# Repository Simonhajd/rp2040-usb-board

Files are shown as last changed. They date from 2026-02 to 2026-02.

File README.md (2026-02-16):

# RP2040 USB Board (12×38mm)

A minimal RP2040 USB device board designed to fit within a 12mm × 38mm footprint, which is roughly the size of a small USB drive.

This project started from an RP2040 reference design and was stripped down to only the systems required for the USB device operation. I changed the flash and power components and entirely redesigned the layout to meet the width constraint, which matches the width of a standard USB port.




Screenshot 2026-02-16 at 4 23 13 PM

---

## What’s On It

* RP2040 (QFN)
* External QSPI flash
* 3.3V regulator
* Native USB interface
* Single status LED
* 2-layer PCB

There's no GPIO breakout since I intended to make a compact reliable RP2040 rather than a development board.

---

## Why

I wanted to see how small a functional RP2040 implementation could reasonably be made while still following the datasheet requirements.

The goal wasn’t to create a dev board, but a compact usb device.

---

## Status

Rev A boards are currently in fabrication and will be tested upon arrival.

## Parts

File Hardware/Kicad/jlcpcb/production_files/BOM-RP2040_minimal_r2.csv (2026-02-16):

Comment | Designator | Footprint | LCSC | Quantity
1u | C10 | C_0402_1005Metric |  | 1
27 | R4 | R_0402_1005Metric |  | 1
100n | C6 | C_0402_1005Metric |  | 1
100n | C12 | C_0402_1005Metric |  | 1
100n | C9 | C_0402_1005Metric |  | 1
27 | R3 | R_0402_1005Metric |  | 1
5.7K | R7 | R_0402_1005Metric |  | 1
AP2112K-3.3TRG1 | U4 | SOT95P285X140-5N |  | 1
4.7U | C1 | C_0402_1005Metric |  | 1
4.7U | C4 | C_0402_1005Metric |  | 1
1u | C8 | C_0402_1005Metric |  | 1
100n | C15 | C_0402_1005Metric |  | 1
5.7K | R6 | R_0402_1005Metric |  | 1
100n | C7 | C_0402_1005Metric |  | 1
ABM8-272-T3 | Y1 | Crystal_SMD_3225-4Pin_3.2x2.5mm |  | 1
100n | C5 | C_0402_1005Metric |  | 1
W25Q128JVS | U2 | Winbond_USON-8-1EP_3x2mm_P0.5mm_EP0.2x1.6mm |  | 1
RP2040 | U3 | RP2040-QFN-56 |  | 1
100n | C14 | C_0402_1005Metric |  | 1
100n | C11 | C_0402_1005Metric |  | 1
1k | R5 | R_0402_1005Metric |  | 1
DNF | R2 | R_0402_1005Metric |  | 1
15p | C3 | C_0402_1005Metric |  | 1
15p | C2 | C_0402_1005Metric |  | 1
100n | C13 | C_0402_1005Metric |  | 1
~ | 1 | USB-C-SMD_TYPE-C-31-G-09 |  | 1
470 | R8 | C_0402_1005Metric |  | 1
LED | D1 | LED_0603_1608Metric |  | 1

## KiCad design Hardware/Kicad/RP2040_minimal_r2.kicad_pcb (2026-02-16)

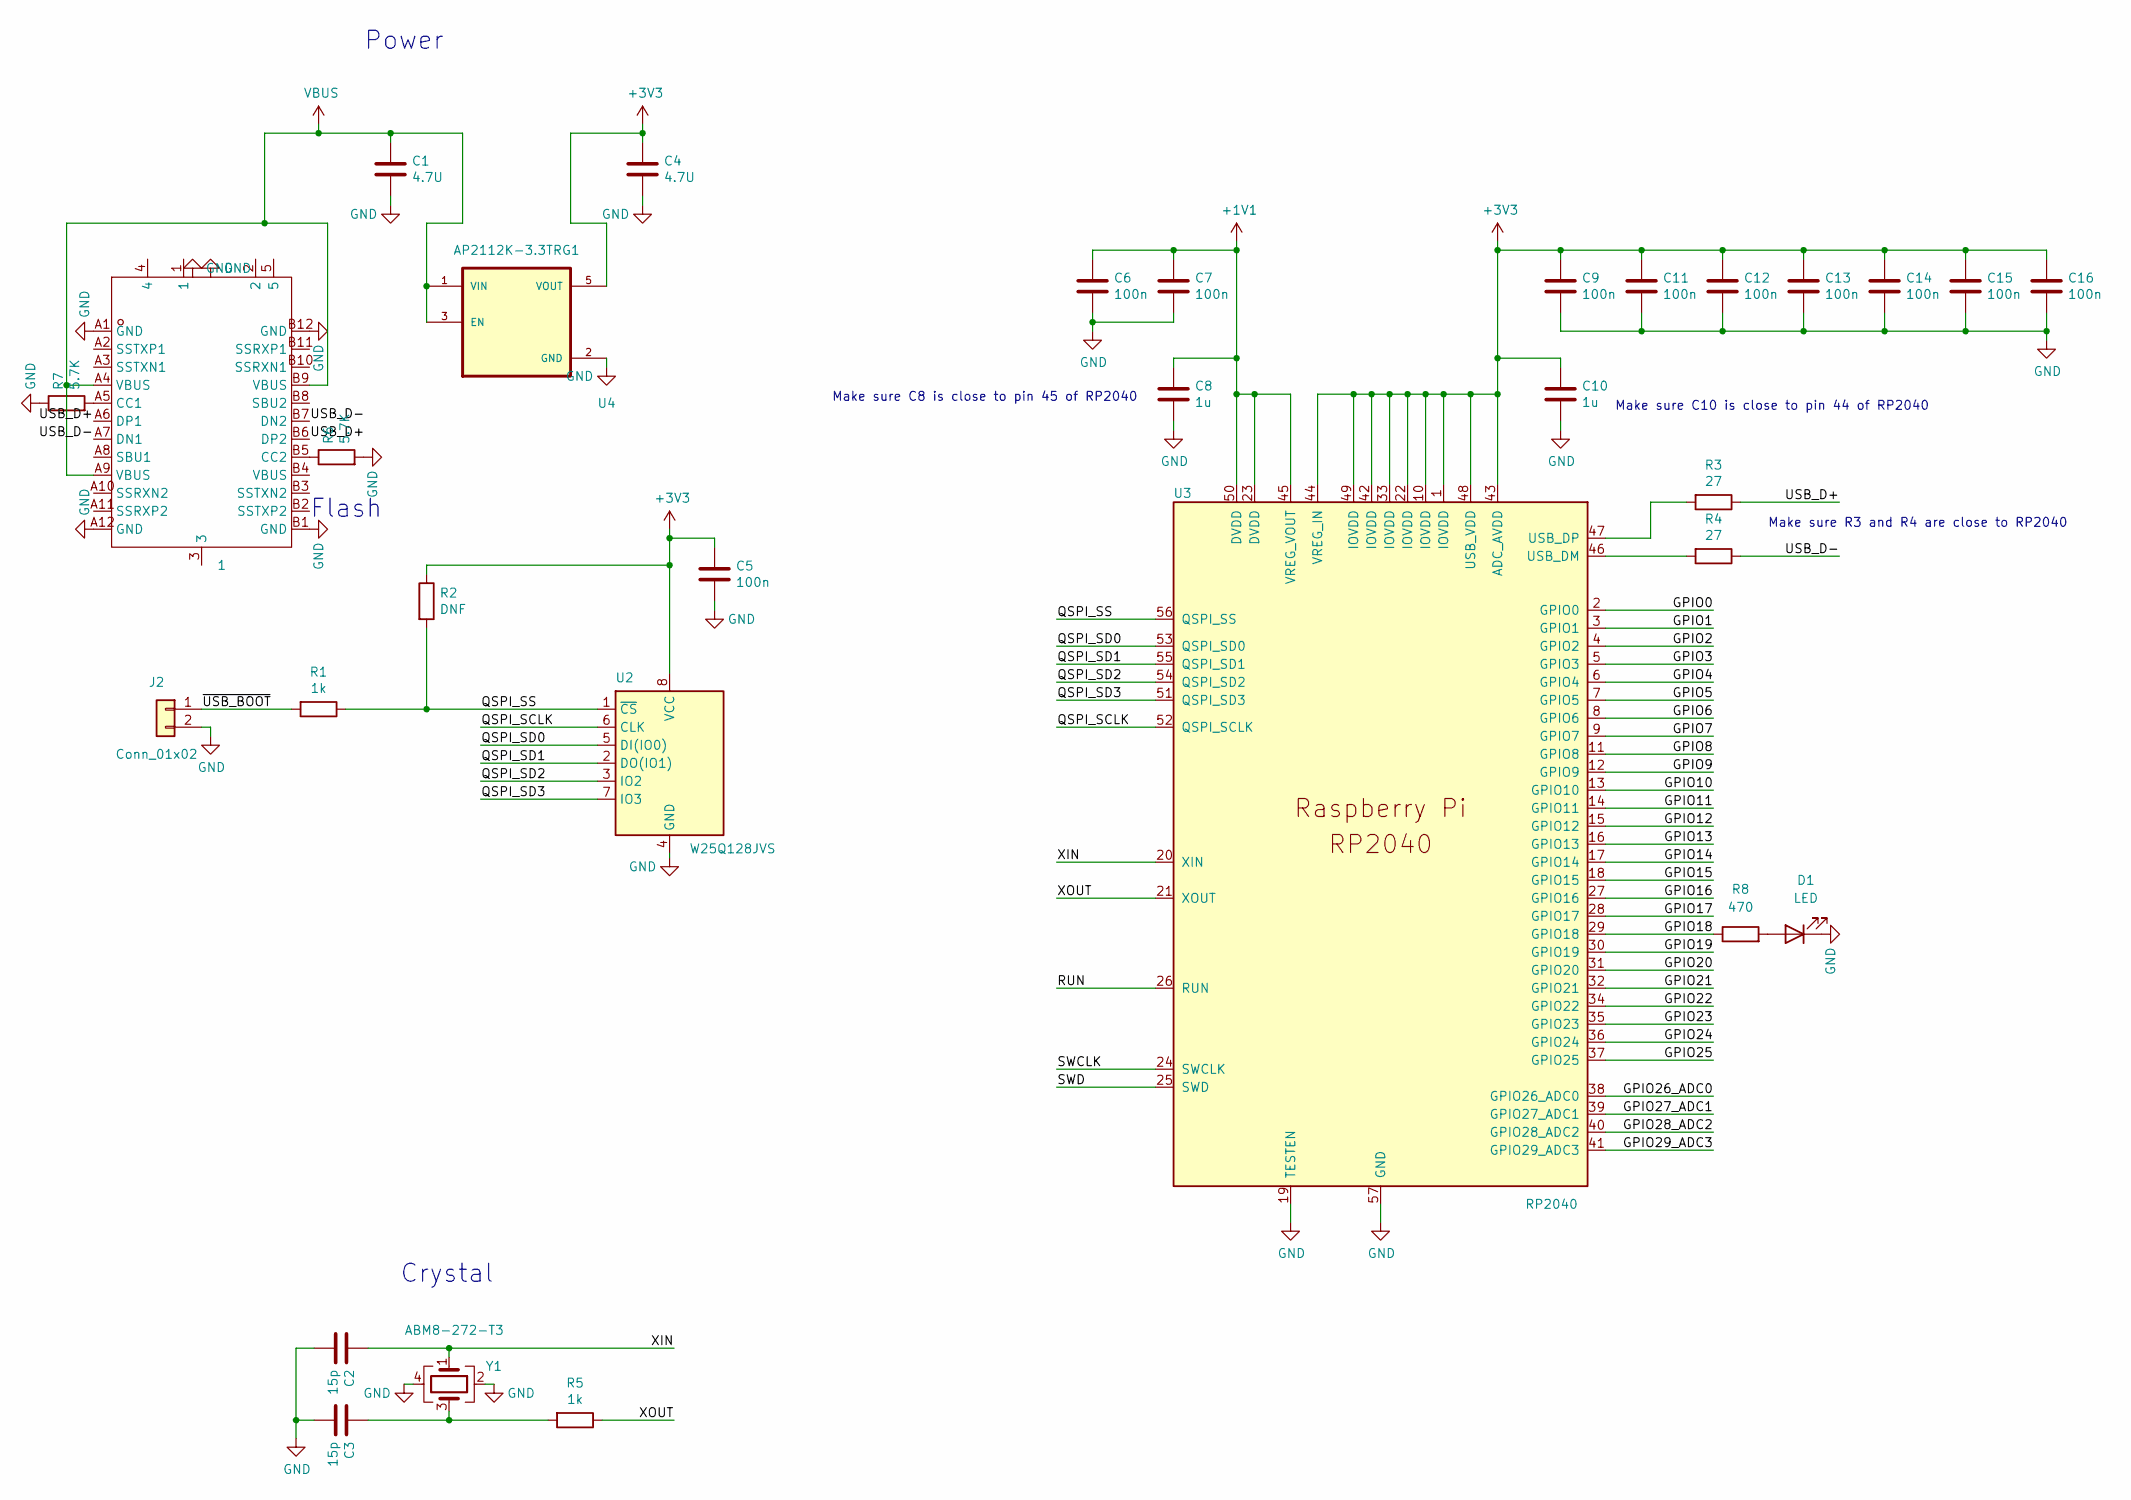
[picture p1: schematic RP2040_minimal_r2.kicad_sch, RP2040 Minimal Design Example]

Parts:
1: (no value)
C1, C4: 4.7U; C_0402_1005Metric
C2, C3: 15p; C_0402_1005Metric
C5, C6, C7, C9, C11, C12, C13, C14, C15, C16: 100n; C_0402_1005Metric
C8, C10: 1u; C_0402_1005Metric
D1: LED; LED_0603_1608Metric
J2: Conn_01x02; PinHeader_1x02_P2.54mm_Vertical
R1, R5: 1k; R_0402_1005Metric
R2: DNF; R_0402_1005Metric
R3, R4: 27; R_0402_1005Metric
R6, R7: 5.7K; R_0402_1005Metric
R8: 470; C_0402_1005Metric
U2: W25Q128JVS; Winbond_USON-8-1EP_3x2mm_P0.5mm_EP0.2x1.6mm
U3: RP2040; RP2040-QFN-56
U4: AP2112K-3.3TRG1; SOT95P285X140-5N; PARTREV 2-2
Y1: ABM8-272-T3; Crystal_SMD_3225-4Pin_3.2x2.5mm

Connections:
+1V1: C6.1, C7.1, C8.1, U3.23 (DVDD), U3.45 (VREG_VOUT), U3.50 (DVDD)
+3V3: C4.1, C5.1, C9.1, C10.1, C11.1, C12.1, C13.1, C14.1, C15.1, C16.1, R2.1, U2.8 (VCC), U3.1 (IOVDD), U3.10 (IOVDD), U3.22 (IOVDD), U3.33 (IOVDD), U3.42 (IOVDD), U3.43 (ADC_AVDD), U3.44 (VREG_IN), U3.48 (USB_VDD), U3.49 (IOVDD), U4.5 (VOUT)
/GPIO0: U3.2 (GPIO0)
/GPIO1: U3.3 (GPIO1)
/GPIO2: U3.4 (GPIO2)
/GPIO3: U3.5 (GPIO3)
/GPIO4: U3.6 (GPIO4)
/GPIO5: U3.7 (GPIO5)
/GPIO6: U3.8 (GPIO6)
/GPIO7: U3.9 (GPIO7)
/GPIO8: U3.11 (GPIO8)
/GPIO9: U3.12 (GPIO9)
/GPIO10: U3.13 (GPIO10)
/GPIO11: U3.14 (GPIO11)
/GPIO12: U3.15 (GPIO12)
/GPIO13: U3.16 (GPIO13)
/GPIO14: U3.17 (GPIO14)
/GPIO15: U3.18 (GPIO15)
/GPIO16: U3.27 (GPIO16)
/GPIO17: U3.28 (GPIO17)
/GPIO18: R8.1, U3.29 (GPIO18)
/GPIO19: U3.30 (GPIO19)
/GPIO20: U3.31 (GPIO20)
/GPIO21: U3.32 (GPIO21)
/GPIO22: U3.34 (GPIO22)
/GPIO23: U3.35 (GPIO23)
/GPIO24: U3.36 (GPIO24)
/GPIO25: U3.37 (GPIO25)
/GPIO26_ADC0: U3.38 (GPIO26_ADC0)
/GPIO27_ADC1: U3.39 (GPIO27_ADC1)
/GPIO28_ADC2: U3.40 (GPIO28_ADC2)
/GPIO29_ADC3: U3.41 (GPIO29_ADC3)
/QSPI_SCLK: U2.6 (CLK), U3.52 (QSPI_SCLK)
/QSPI_SD0: U2.5 (DI(IO0)), U3.53 (QSPI_SD0)
/QSPI_SD1: U2.2 (DO(IO1)), U3.55 (QSPI_SD1)
/QSPI_SD2: U2.3 (IO2), U3.54 (QSPI_SD2)
/QSPI_SD3: U2.7 (IO3), U3.51 (QSPI_SD3)
/QSPI_SS: R1.1, R2.2, U2.1 (~CS), U3.56 (QSPI_SS)
/RUN: U3.26 (RUN)
/SWCLK: U3.24 (SWCLK)
/SWD: U3.25 (SWD)
/USB_D+: 1.A6 (DP1), 1.B6 (DP2), R3.1
/USB_D-: 1.A7 (DN1), 1.B7 (DN2), R4.1
/XIN: C2.1, U3.20 (XIN), Y1.1
/XOUT: R5.1, U3.21 (XOUT)
GND: 1.A1 (GND), 1.A12 (GND), 1.B1 (GND), 1.B12 (GND), C1.2, C2.2, C3.2, C4.2, C5.2, C6.2, C7.2, C8.2, C9.2, C10.2, C11.2, C12.2, C13.2, C14.2, C15.2, C16.2, D1.1 (K), J2.2, R6.2, R7.1, U2.4 (GND), U3.19 (TESTEN), U3.57 (GND), U4.2 (GND), Y1.2, Y1.4
unnamed: 1.A5 (CC1), R7.2
unnamed: 1.B5 (CC2), R6.1
unnamed: C3.1, R5.2, Y1.3
unnamed: D1.2 (A), R8.2
unnamed: J2.1, R1.2
unnamed: R4.2, U3.46 (USB_DM)
unnamed: R3.2, U3.47 (USB_DP)
VBUS: 1.A4 (VBUS), 1.A9 (VBUS), 1.B9 (VBUS), C1.1, U4.1 (VIN), U4.3 (EN)

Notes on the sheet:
Power
Crystal
Make sure C8 is close to pin 45 of RP2040
Make sure C10 is close to pin 44 of RP2040
Make sure R3 and R4 are close to RP2040
Flash

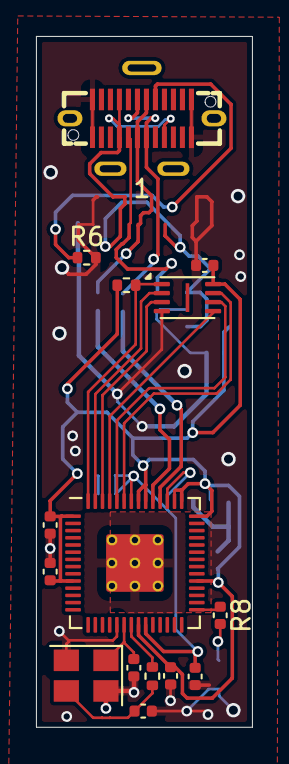
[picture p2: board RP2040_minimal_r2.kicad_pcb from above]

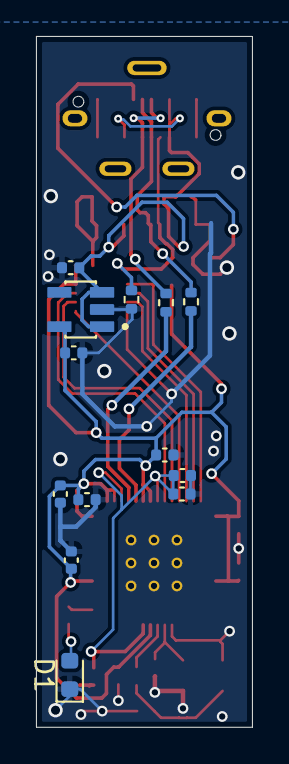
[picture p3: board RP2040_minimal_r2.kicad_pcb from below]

Board: 2 copper layers, 12.0 x 38.4 mm, 28 parts (13 on the bottom side), 21 nets.
